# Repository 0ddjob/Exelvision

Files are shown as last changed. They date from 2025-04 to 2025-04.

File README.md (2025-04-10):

# Exelvision EXL100
Hardware projects and other info for the French Exelvision EXL100 computer.<br>
It has the following main ICs:
- Texas Instruments TMS4408 ... 8k x 4bit giving 32KBytes of shared VRAM
- NEC D4016 ... 2KByte SRAM for CPU RAM
- Texas Instruments TAL004 ... Gate Array
- Texas Instruments L30002N ... TMS 7220 CPU
- Texas Instruments C34802N ... TMS 7041 peripheral co-processor
- Texas Instruments TMP5220CNL ... TMS 5220 speech synthesiser
- Texas Instruments TMX3556NS ... TMS 3556 video display processor (VDP)

The ROM cartridge connector is a BURNDY PWBH14DER1A-1 which I can't find any info on - it's a 2x14 design.<br>

## YouTube Videos
- [Part 1: First Look](https://youtu.be/5-ew3FQ9LnI)
- [Part 2: Cartridge Pinout](https://youtu.be/ktFMq2L3tBw)
- [Simple Kicad For Simple Vintage Computer Hobbyists: Part 4 (ROM Cartridge Design)](https://youtu.be/4mT13-wXdjI)
- [Part 3: DIY Cartridges](https://youtu.be/ecWkOvze2gc)

## [EXLROM - Multi-ROM cartridge](/EXLROM/)
The EXL100 could accept ROM cartridges from 8KByte to 32KByte in size, including BASIC.  By using a 4Mbit ROM (27C040) we can fit all known ROMs onto one cartridge.  How exciting.<br>
I've designed two versions: a simple 256kbit version that will hold a single 32KByte ROM (like the olden days) and the 4Mbit version that will hold up to 16 32KByte ROMs.<br>
### Status
- 1-Apr-2025:  Pending test fabrication 
- 10-Apr-2025: Test PCBs arrived & verified! Refer YouTube video.

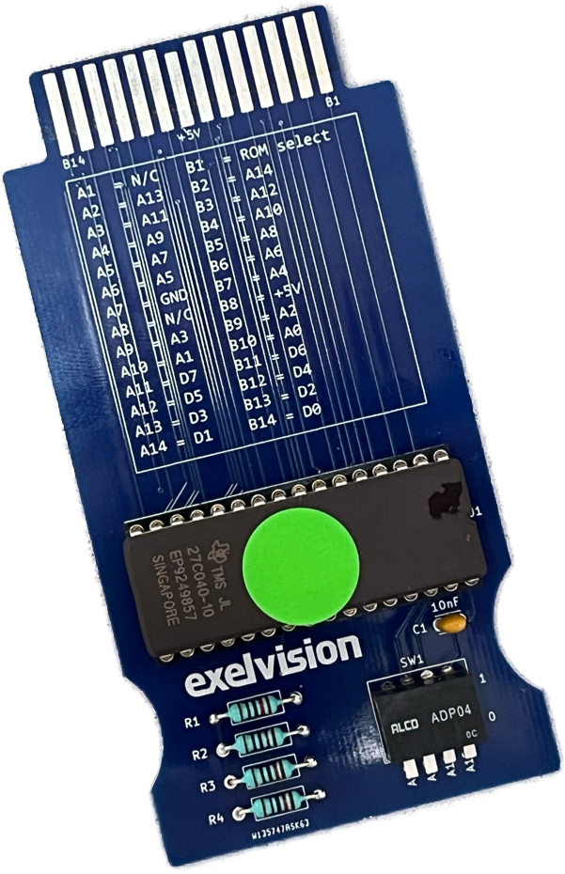
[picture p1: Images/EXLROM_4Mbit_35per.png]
EXLROM 4MBit cartridge


## Partial TAL004 Gate Array Pinout
From cartridge pinout investigation ... <br>
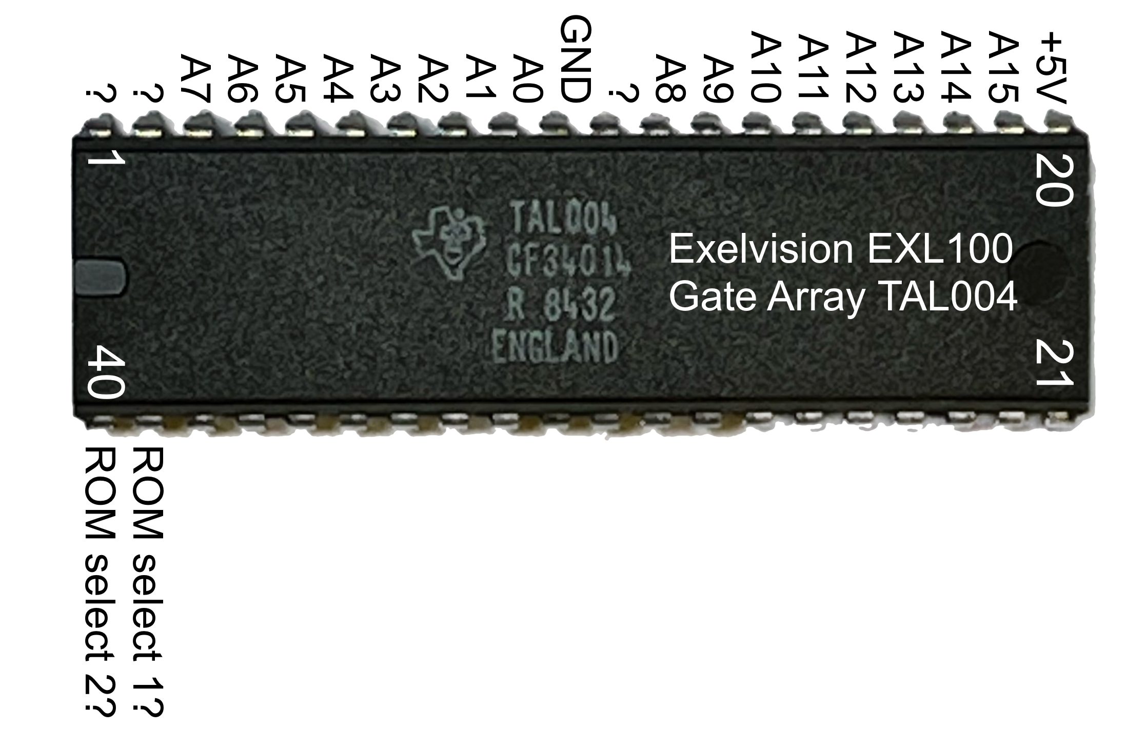
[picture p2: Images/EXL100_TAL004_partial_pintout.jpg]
TAL004 partial pinout


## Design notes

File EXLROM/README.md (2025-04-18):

# EXLROM Multi-ROM Cartridge
## Summary
The Exelvision EXL100 (and Exeltel) cartridge port pinout is below - the B-side face up and A-side face down when the cartridge is inserted.<br>
The pinout was determined from the 32KByte Tennis cartridge.  The A1 pin was not connected in this cartridge but is connected to pin 40 of the TAL004 gate array ... perhaps a 2nd ROM select line?<br>
```
A1 = ROMCS2(?)  B1 = ROMCS1
A2 = A13        B2 = A14
A3 = A11        B3 = A12
A4 = A9         B4 = A10
A5 = A7         B5 = A8
A6 = A5         B6 = A6
A7 = GND        B7 = A4
A8 = N/C        B8 = +5V
A9 = A3         B9 = A2
A10 = A1        B10 = A0
A11 = D7        B11 = D6
A12 = D5        B12 = D4
A13 = D3        B13 = D2
A14 = D1        B14 = D0
```
## [Simple Single ROM Version](/EXLROM/EXLROM_256Kbit/)
This version takes a 32KByte 27C256 EPROM that will fit a single 32KByte ROM.  The smaller 8KByte and 16KByte ROMs will just have empty space.<br>

## [Multi-ROM](/EXLROM/EXLROM_4Mbit/)
This version should fit all known Exelvision ROMs.<br>

## Bank Selection
Using a 4MBit EPROM allows us to fit 16 32KByte ROMs selectable via four dip switches that determine the value of the A15 to A18 address lines.  A single ROM can be created by concatenating 32KByte ROMs into one file - very simply done in Linux or Windows via command line.  Smaller ROMs (8KByte and 16KByte) can be duplcated (i.e. four concatenated copies of the 8KByte ROM) to bring their size up to 32KBytes.
```
AAAA 
1111
8765 Bank  ROM Address Range
---- ----  -----------------
0000    0  0x00000-0x07FFF
0001    1  0x08000-0x0FFFF
0010    2  0x10000-0x17FFF
0011    3  0x18000-0x1FFFF
0100    4  0x20000-0x27FFF
0101    5  0x28000-0x2FFFF
0110    6  0x30000-0x37FFF
0111    7  0x38000-0x3FFFF
1000    8  0x40000-0x47FFF
1001    9  0x48000-0x4FFFF
1010   10  0x50000-0x57FFF
1011   11  0x58000-0x5FFFF
1100   12  0x60000-0x67FFF
1101   13  0x68000-0x6FFFF
1110   14  0x70000-0x77FFF
1111   15  0x78000-0x7FFFF
```
## Cartridge Pinout
The B-side that faces up when inserted.  Pins are numbered B1 on the right to B14 on left.<br>
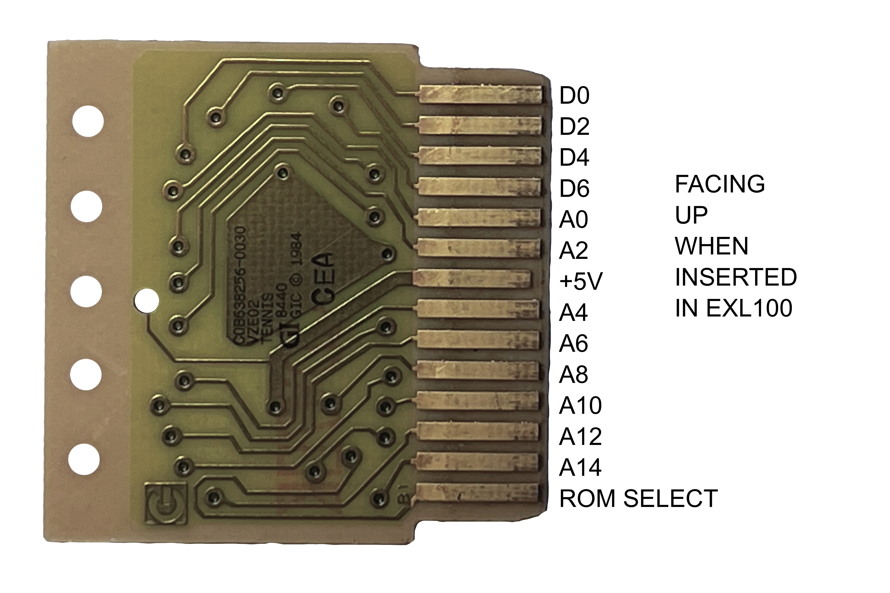
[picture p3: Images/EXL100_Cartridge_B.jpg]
Cartridge B-side

The A-side that faces down when inserted.  Pins are numbered A1 on the right and A14 on the left.<br>
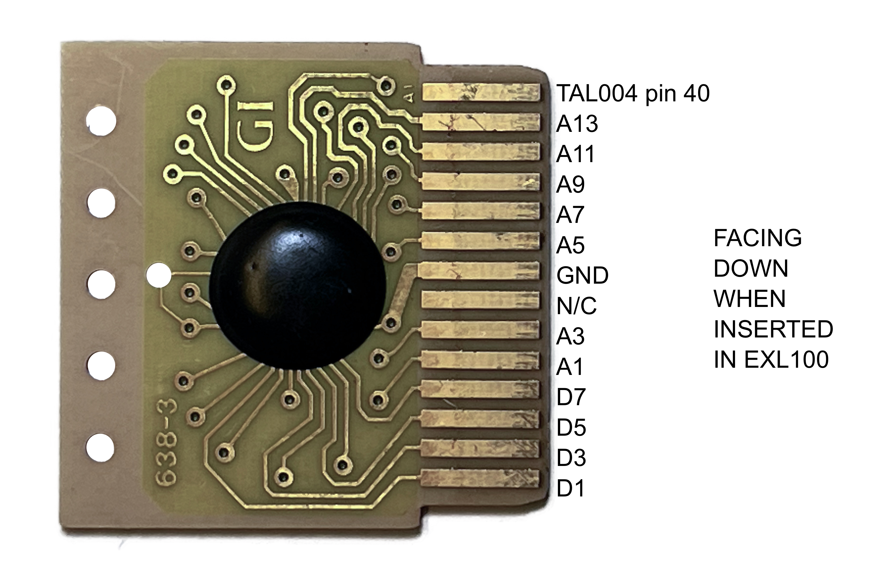
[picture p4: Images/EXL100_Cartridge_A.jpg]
Cartridge A-side


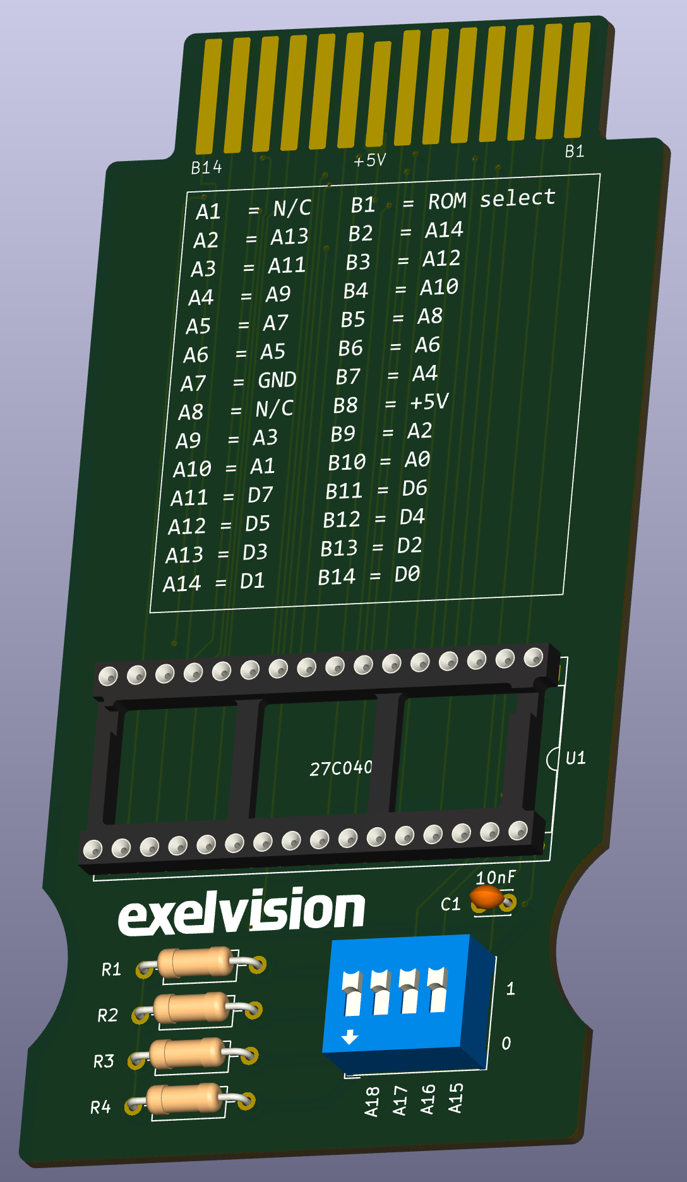
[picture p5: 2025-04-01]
Images/EXLROM_4Mbit_3D.png

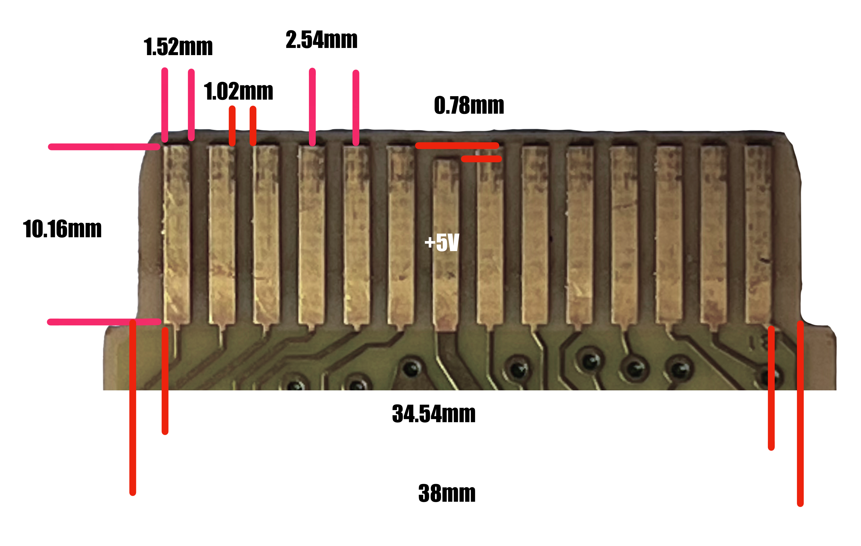
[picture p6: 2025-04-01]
Images/EXL100_Cartridge_dimensions.jpg

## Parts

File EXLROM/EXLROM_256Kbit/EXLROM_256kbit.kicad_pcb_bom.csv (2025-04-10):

Designator | Quantity | Value | Footprint | Package | MPN | DNP | Mount_Type | Description
C1 | 1 | 100nF | C_Disc_D3.0mm_W2.0mm_P2.50mm |  |  |  | tht | Unpolarized capacitor
J1 | 1 | EXL100 Cartridge | EXL100_Cartridge |  |  |  | tht
U1 | 1 | 27C256 | DIP-28_W15.24mm |  |  |  | tht | OTP EPROM 256 KiBit

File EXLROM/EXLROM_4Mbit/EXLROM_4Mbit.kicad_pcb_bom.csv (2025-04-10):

Designator | Quantity | Value | Footprint | Package | MPN | DNP | Mount_Type | Description
C1 | 1 | 100nF | C_Disc_D3.0mm_W2.0mm_P2.50mm |  |  |  | tht | Unpolarized capacitor
J1 | 1 | EXL100 Cartridge | EXL100_Cartridge |  |  |  | tht
R1, R2, R3, R4 | 4 | 10KΩ | R_Axial_DIN0207_L6.3mm_D2.5mm_P10.16mm_Horizontal |  |  |  | tht | Resistor
SW1 | 1 | SW_DIP_x04 | SW_DIP_SPSTx04_Slide_9.78x12.34mm_W7.62mm_P2.54mm |  |  |  | tht | 4x DIP Switch, Single Pole Single Throw (SPST) switch, small symbol
U1 | 1 | 27C040 | DIP-32_W15.24mm_Socket |  |  |  | tht | OTP EPROM 4 MiBit (512 Ki x 8)

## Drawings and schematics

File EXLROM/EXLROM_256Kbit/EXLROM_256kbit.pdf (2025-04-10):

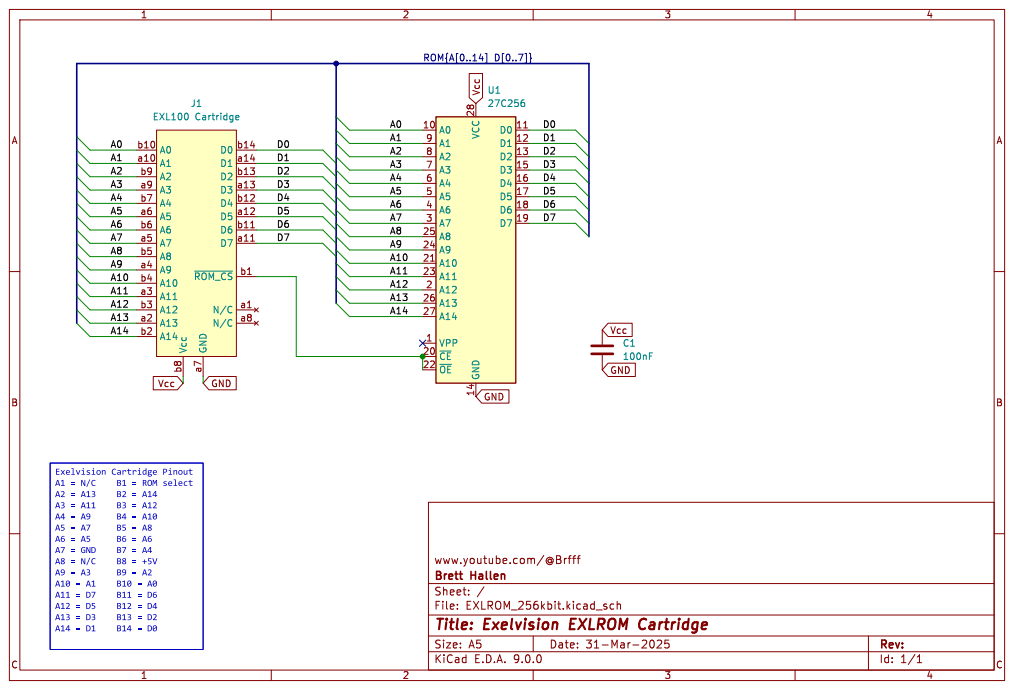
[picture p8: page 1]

Id: 1/1 Title: Exelvision EXLROM Cartridge

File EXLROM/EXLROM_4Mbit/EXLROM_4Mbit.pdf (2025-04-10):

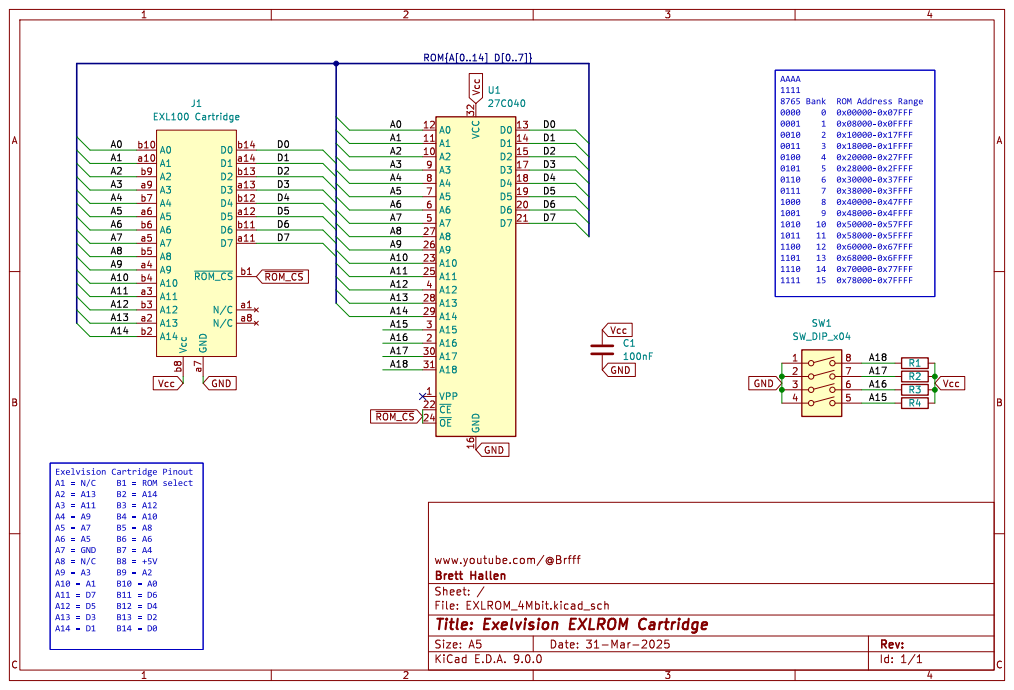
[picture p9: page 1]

Id: 1/1 Title: Exelvision EXLROM Cartridge

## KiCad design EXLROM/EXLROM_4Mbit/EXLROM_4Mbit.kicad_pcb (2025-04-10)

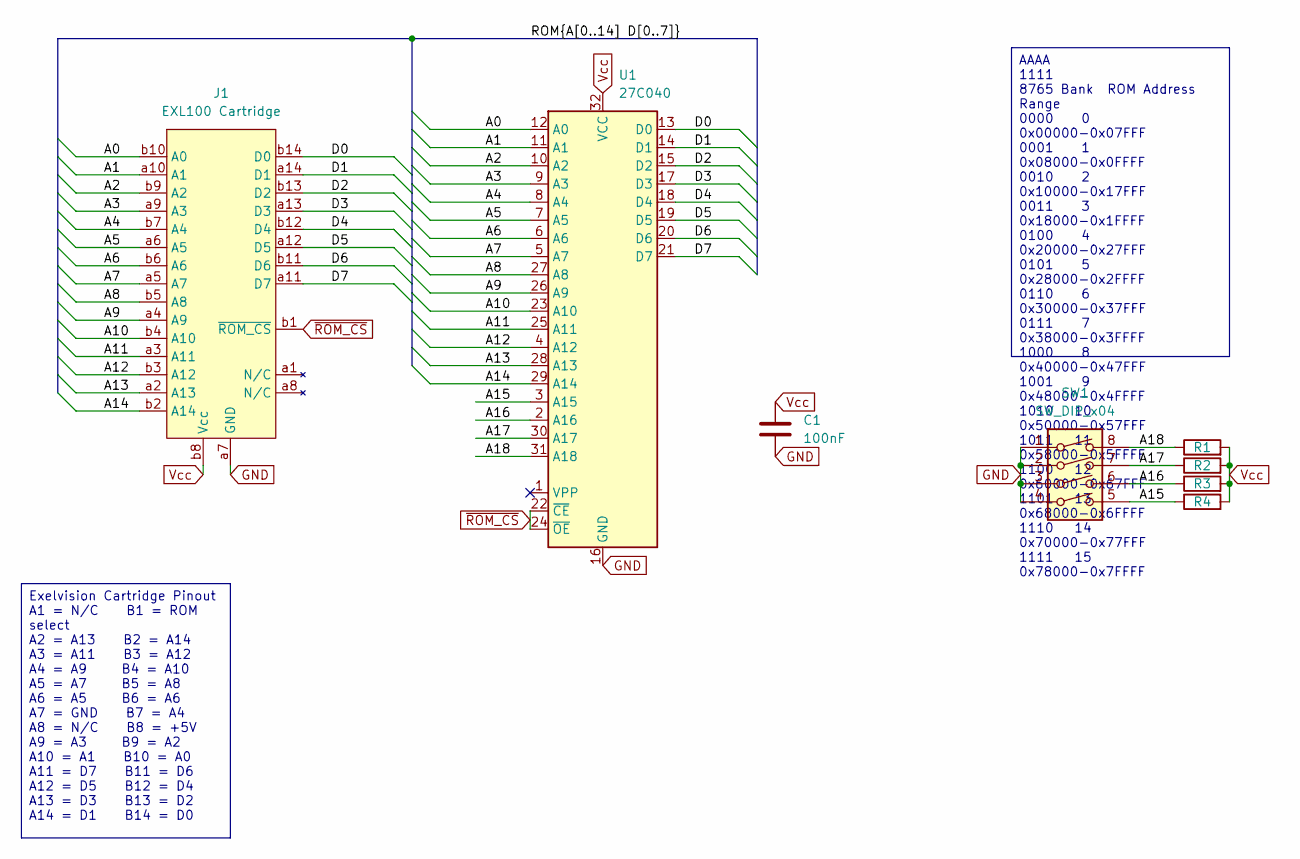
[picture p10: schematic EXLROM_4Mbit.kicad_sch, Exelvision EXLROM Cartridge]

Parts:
C1: 100nF; C_Disc_D3.0mm_W2.0mm_P2.50mm
J1: EXL100 Cartridge; EXL100_Cartridge
R1, R2, R3, R4: 10KΩ; R_Axial_DIN0207_L6.3mm_D2.5mm_P10.16mm_Horizontal
SW1: SW_DIP_x04; SW_DIP_SPSTx04_Slide_9.78x12.34mm_W7.62mm_P2.54mm
U1: 27C040; DIP-32_W15.24mm_Socket

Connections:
/A0: J1.b10 (A0), U1.12 (A0)
/A1: J1.a10 (A1), U1.11 (A1)
/A2: J1.b9 (A2), U1.10 (A2)
/A3: J1.a9 (A3), U1.9 (A3)
/A4: J1.b7 (A4), U1.8 (A4)
/A5: J1.a6 (A5), U1.7 (A5)
/A6: J1.b6 (A6), U1.6 (A6)
/A7: J1.a5 (A7), U1.5 (A7)
/A8: J1.b5 (A8), U1.27 (A8)
/A9: J1.a4 (A9), U1.26 (A9)
/A10: J1.b4 (A10), U1.23 (A10)
/A11: J1.a3 (A11), U1.25 (A11)
/A12: J1.b3 (A12), U1.4 (A12)
/A13: J1.a2 (A13), U1.28 (A13)
/A14: J1.b2 (A14), U1.29 (A14)
/A15: R4.1, SW1.5, U1.3 (A15)
/A16: R3.1, SW1.6, U1.2 (A16)
/A17: R2.1, SW1.7, U1.30 (A17)
/A18: R1.1, SW1.8, U1.31 (A18)
/D0: J1.b14 (D0), U1.13 (D0)
/D1: J1.a14 (D1), U1.14 (D1)
/D2: J1.b13 (D2), U1.15 (D2)
/D3: J1.a13 (D3), U1.17 (D3)
/D4: J1.b12 (D4), U1.18 (D4)
/D5: J1.a12 (D5), U1.19 (D5)
/D6: J1.b11 (D6), U1.20 (D6)
/D7: J1.a11 (D7), U1.21 (D7)
GND: C1.2, J1.a7 (GND), SW1.1, SW1.2, SW1.3, SW1.4, U1.16 (GND)
Vcc: C1.1, J1.b8 (Vcc), R1.2, R2.2, R3.2, R4.2, U1.32 (VCC)
~ROM_CS: J1.b1 (~ROM_CS), U1.22 (~CE), U1.24 (~OE)

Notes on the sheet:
Exelvision Cartridge Pinout A1 = N/C B1 = ROM select A2 = A13 B2 = A14 A3 = A11 B3 = A12 A4 = A9 B4 = A10 A5 = A7 B5 = A8 A6 = A5 B6 = A6 A7 = GND B7 = A4 A8 = N/C B8 = +5V A9 = A3 B9 = A2 A10 = A1 B10 = A0 A11 = D7 B11 = D6 A12 = D5 B12 = D4 A13 = D3 B13 = D2 A14 = D1 B14 = D0
AAAA 1111 8765 Bank ROM Address Range 0000 0 0x00000-0x07FFF 0001 1 0x08000-0x0FFFF 0010 2 0x10000-0x17FFF 0011 3 0x18000-0x1FFFF 0100 4 0x20000-0x27FFF 0101 5 0x28000-0x2FFFF 0110 6 0x30000-0x37FFF 0111 7 0x38000-0x3FFFF 1000 8 0x40000-0x47FFF 1001 9 0x48000-0x4FFFF 1010 10 0x50000-0x57FFF 1011 11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

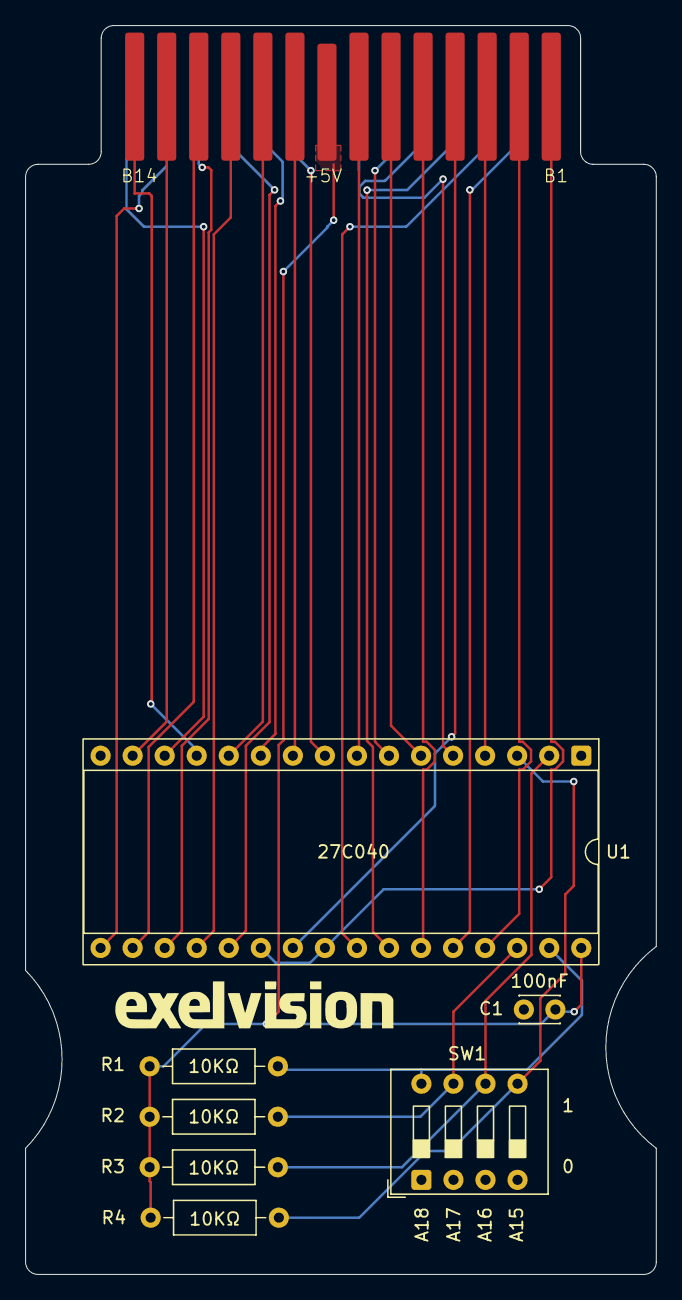
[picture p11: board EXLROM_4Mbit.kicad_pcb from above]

Board: 2 copper layers, 50.0 x 99.0 mm, 8 parts (0 on the bottom side), 30 nets.

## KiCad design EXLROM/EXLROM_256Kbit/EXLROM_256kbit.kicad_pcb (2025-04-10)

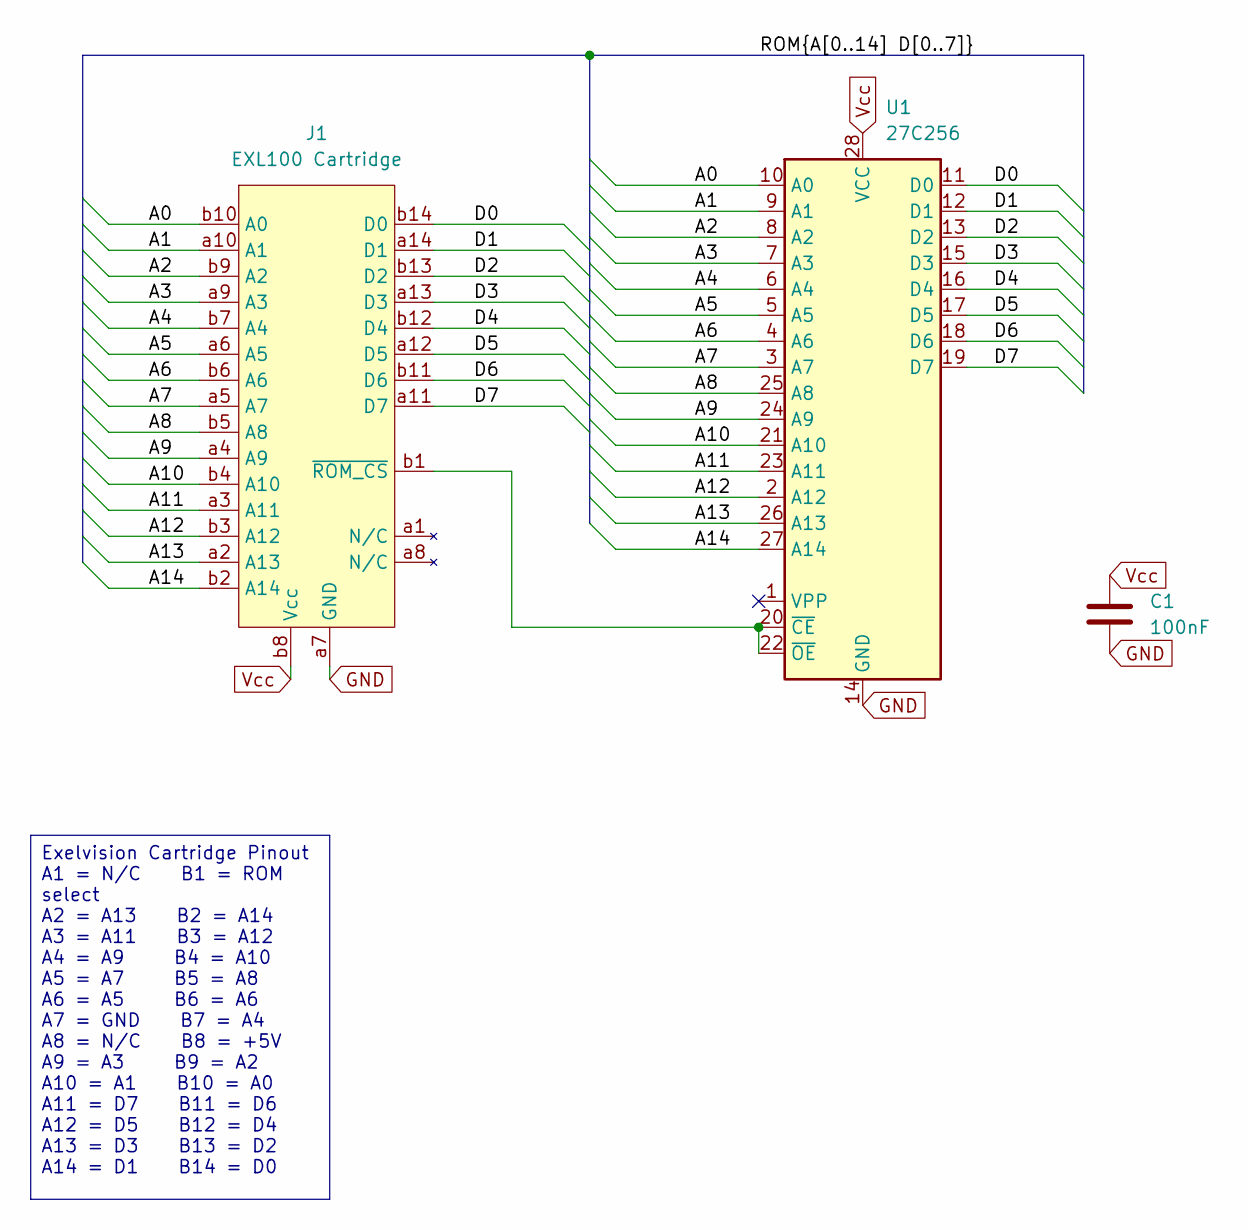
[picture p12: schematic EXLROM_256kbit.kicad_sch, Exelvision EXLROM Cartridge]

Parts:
C1: 100nF; C_Disc_D3.0mm_W2.0mm_P2.50mm
J1: EXL100 Cartridge; EXL100_Cartridge
U1: 27C256; DIP-28_W15.24mm

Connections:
/A0: J1.b10 (A0), U1.10 (A0)
/A1: J1.a10 (A1), U1.9 (A1)
/A2: J1.b9 (A2), U1.8 (A2)
/A3: J1.a9 (A3), U1.7 (A3)
/A4: J1.b7 (A4), U1.6 (A4)
/A5: J1.a6 (A5), U1.5 (A5)
/A6: J1.b6 (A6), U1.4 (A6)
/A7: J1.a5 (A7), U1.3 (A7)
/A8: J1.b5 (A8), U1.25 (A8)
/A9: J1.a4 (A9), U1.24 (A9)
/A10: J1.b4 (A10), U1.21 (A10)
/A11: J1.a3 (A11), U1.23 (A11)
/A12: J1.b3 (A12), U1.2 (A12)
/A13: J1.a2 (A13), U1.26 (A13)
/A14: J1.b2 (A14), U1.27 (A14)
/D0: J1.b14 (D0), U1.11 (D0)
/D1: J1.a14 (D1), U1.12 (D1)
/D2: J1.b13 (D2), U1.13 (D2)
/D3: J1.a13 (D3), U1.15 (D3)
/D4: J1.b12 (D4), U1.16 (D4)
/D5: J1.a12 (D5), U1.17 (D5)
/D6: J1.b11 (D6), U1.18 (D6)
/D7: J1.a11 (D7), U1.19 (D7)
GND: C1.2, J1.a7 (GND), U1.14 (GND)
unnamed: J1.b1 (~ROM_CS), U1.20 (~CE), U1.22 (~OE)
Vcc: C1.1, J1.b8 (Vcc), U1.28 (VCC)

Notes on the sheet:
Exelvision Cartridge Pinout A1 = N/C B1 = ROM select A2 = A13 B2 = A14 A3 = A11 B3 = A12 A4 = A9 B4 = A10 A5 = A7 B5 = A8 A6 = A5 B6 = A6 A7 = GND B7 = A4 A8 = N/C B8 = +5V A9 = A3 B9 = A2 A10 = A1 B10 = A0 A11 = D7 B11 = D6 A12 = D5 B12 = D4 A13 = D3 B13 = D2 A14 = D1 B14 = D0

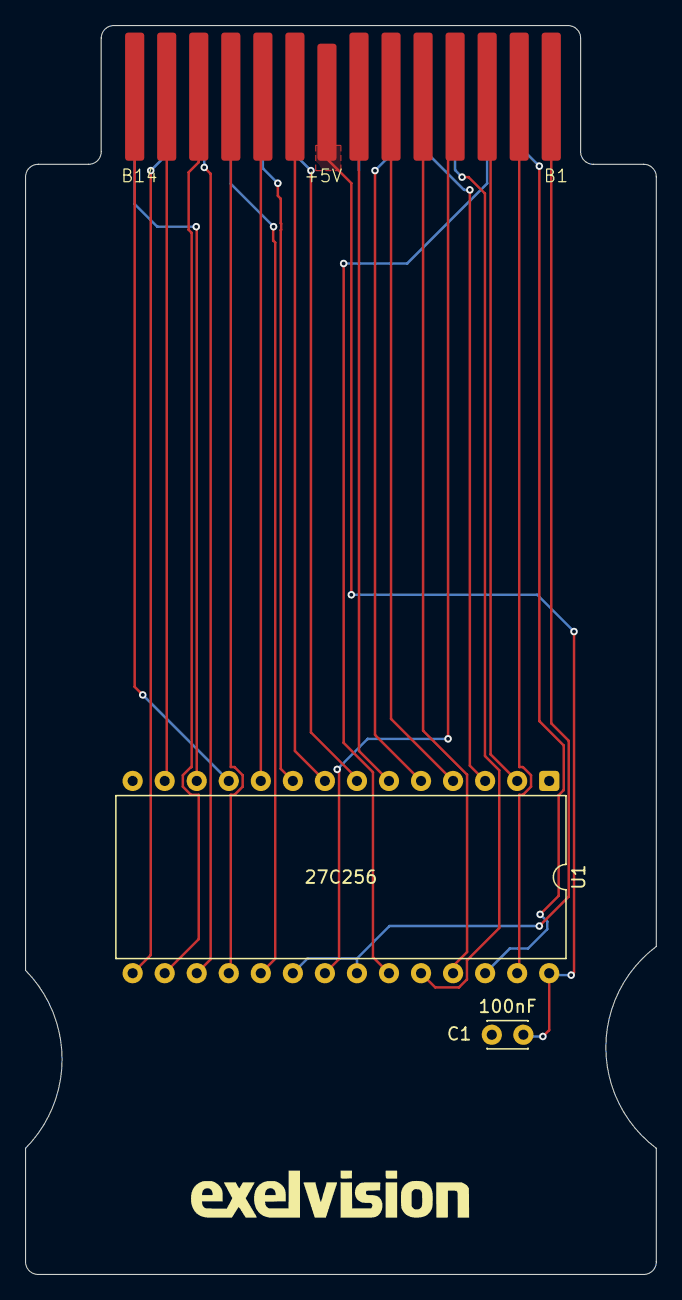
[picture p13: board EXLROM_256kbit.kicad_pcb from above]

Board: 2 copper layers, 50.0 x 99.0 mm, 3 parts (0 on the bottom side), 26 nets.

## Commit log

2025-04-01 Added 256kbit version
    [EXLROM_256kbit.kicad_pcb, EXLROM_256kbit.kicad_sch, EXLROM_4Mbit.kicad_pcb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]
2025-04-01 PCB silkscreen update
    [EXLROM_256kbit.kicad_pcb, EXLROM_4Mbit.kicad_pcb]
2025-04-10 Added ROMs & corrected silkscreen
    [EXLROM_256kbit.kicad_pcb, EXLROM_256kbit.kicad_sch, EXLROM_4Mbit.kicad_pcb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]
2025-04-10 Added additional fabrication-related files
    [EXLROM_256kbit.kicad_pcb_bom.csv, EXLROM_256kbit.kicad_pcb_positions.csv, EXLROM_4Mbit.kicad_pcb_bom.csv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]
